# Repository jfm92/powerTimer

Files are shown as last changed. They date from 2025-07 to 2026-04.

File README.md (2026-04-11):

# Power Timer

## Project Description

The Power Timer is an ultra-low power module that allows you to control the output power by software. It is mainly based on a Real-Time Clock (RTC) and an RS circuit. Thanks to the RTC, you can control the exact wake-up date or the periodicity. It also allows for external interruptions, which gives you the benefits of ultra-low power consumption while being able to connect other types of sensors. The module is based on the RV3028-C7 chip. It is also compatible with Arduino, thanks to its custom library.

The sleep current of the module is around 50nA at 3.3V, making it ideal for battery-powered applications.



## Consumption comparison:

Demo with software **sleep modes**:

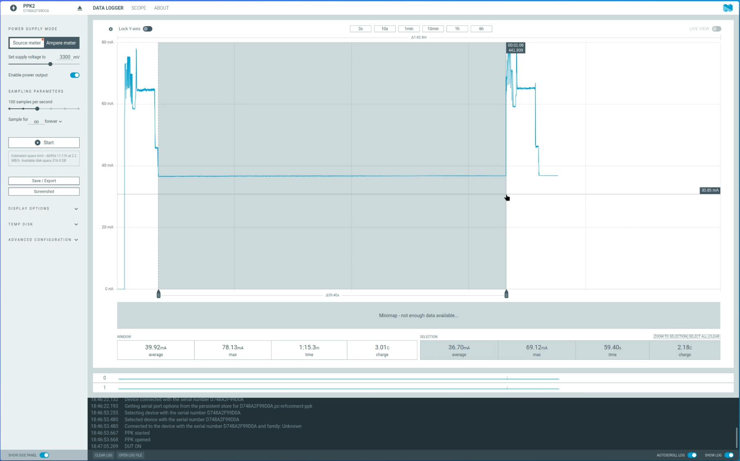
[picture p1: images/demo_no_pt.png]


Same demo **with powerTimer**:

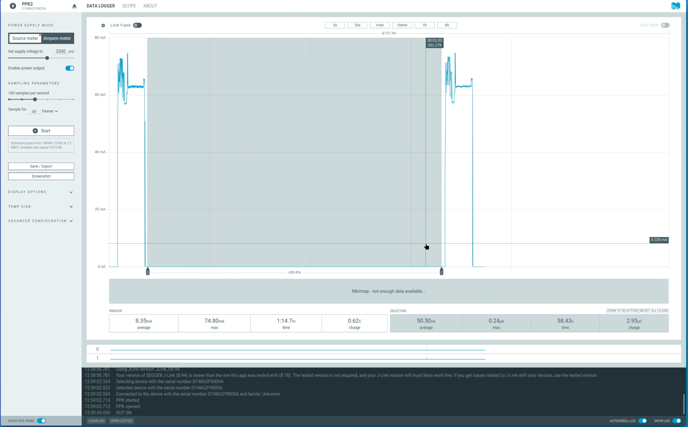
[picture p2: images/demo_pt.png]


### 734.000 times less idle consumption!

## How it works

The module is designed to be a versatile power control unit for your projects. It can be used as a simple timer to power on a device at a specific time or periodically, or it can be used as a power management unit that can be woken up by external events.

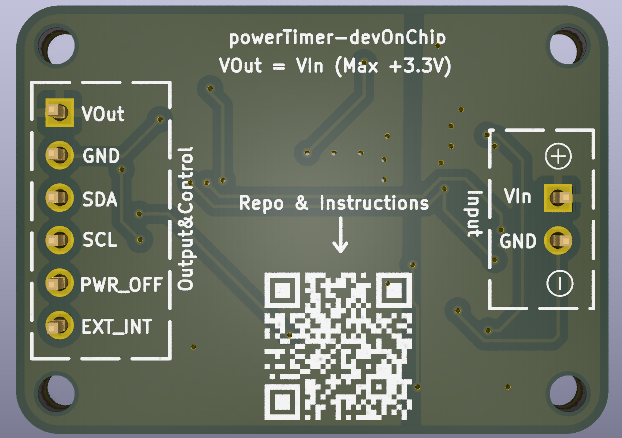
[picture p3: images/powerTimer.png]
Power Timer Diagram


The PCB is divided into two parts:

*   **Input:** The input voltage (VINput) can be from 1.1V to 5.5V. This wide input range makes it compatible with a variety of power sources, from a single-cell Li-Po battery to a 5V power supply.

*   **Output:**
    *   **I2C:** The I2C pins (SDA and SCL) are used to program the RV3028-C7 RTC. You can set the time, date, and alarms using any microcontroller with I2C capabilities.
    *   **VOutput:** This pin will provide the same voltage as the input. When the module is in the "ON" state, the VOutput pin is connected to the VINput pin, providing power to your external device.
    *   **PWR_OFF:** This input allows you to externally cut off the power of the module. By pulling this pin high, you can force the module into the "OFF" state, even if the RTC alarm is active.
    *   **EXT_INT:** This input allows you to wake up the module externally using another sensor. This is useful for applications where you want to wake up the main device based on an external event, such as a button press or a sensor reading.
    *   **On-board button:** A push button is available on the board for manual wake-up. This allows you to turn on the module without relying on the RTC alarm or an external interrupt.

The logic levels of the I2C bus and the external interrupt input depend on the selected input voltage.

## Schematic

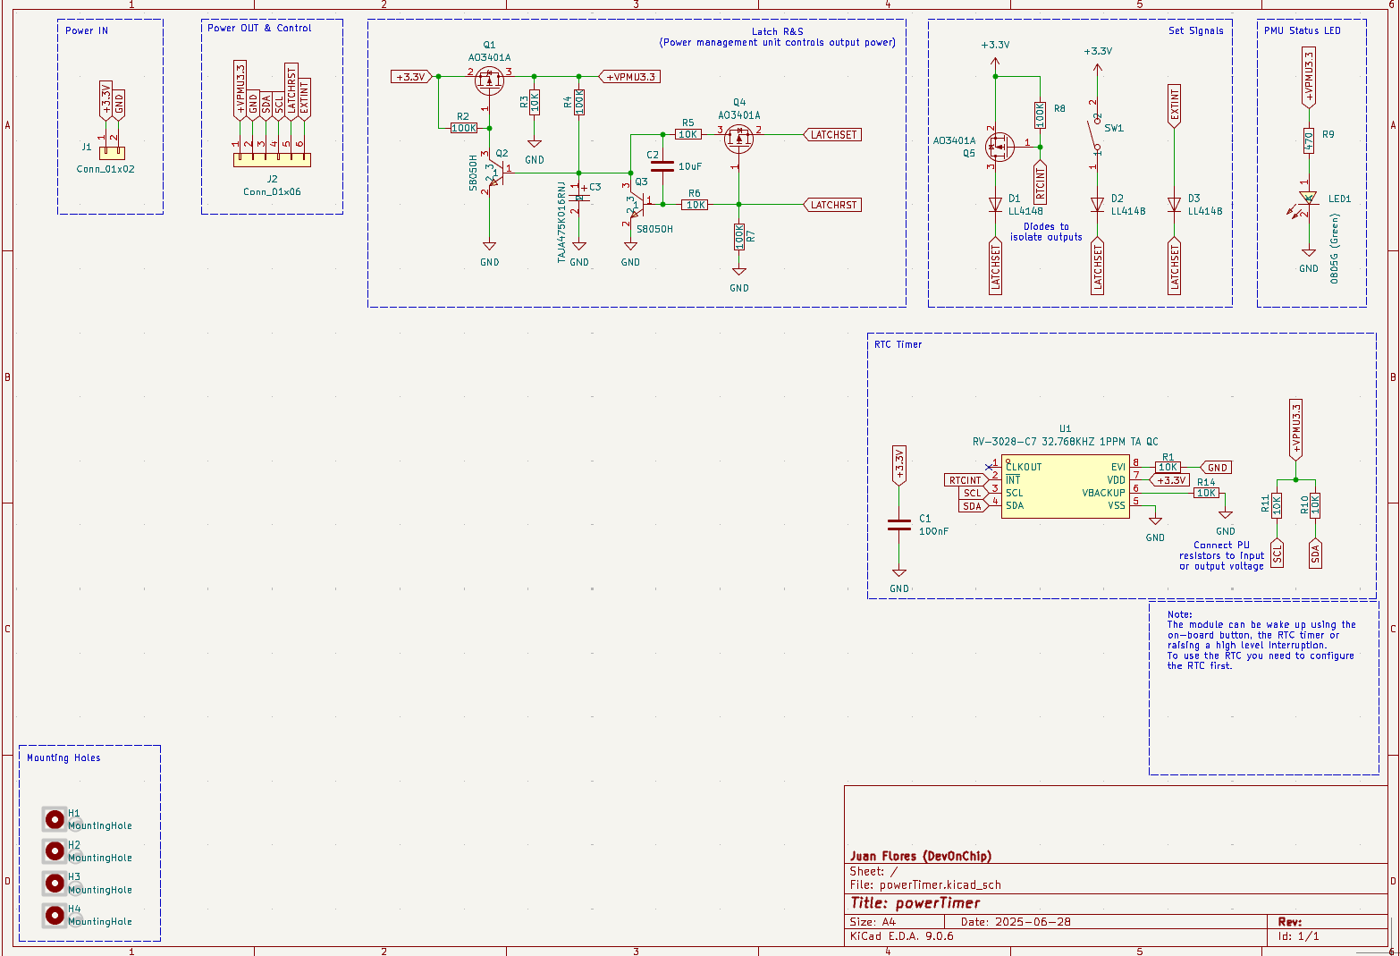
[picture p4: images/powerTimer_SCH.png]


## PCB Layout

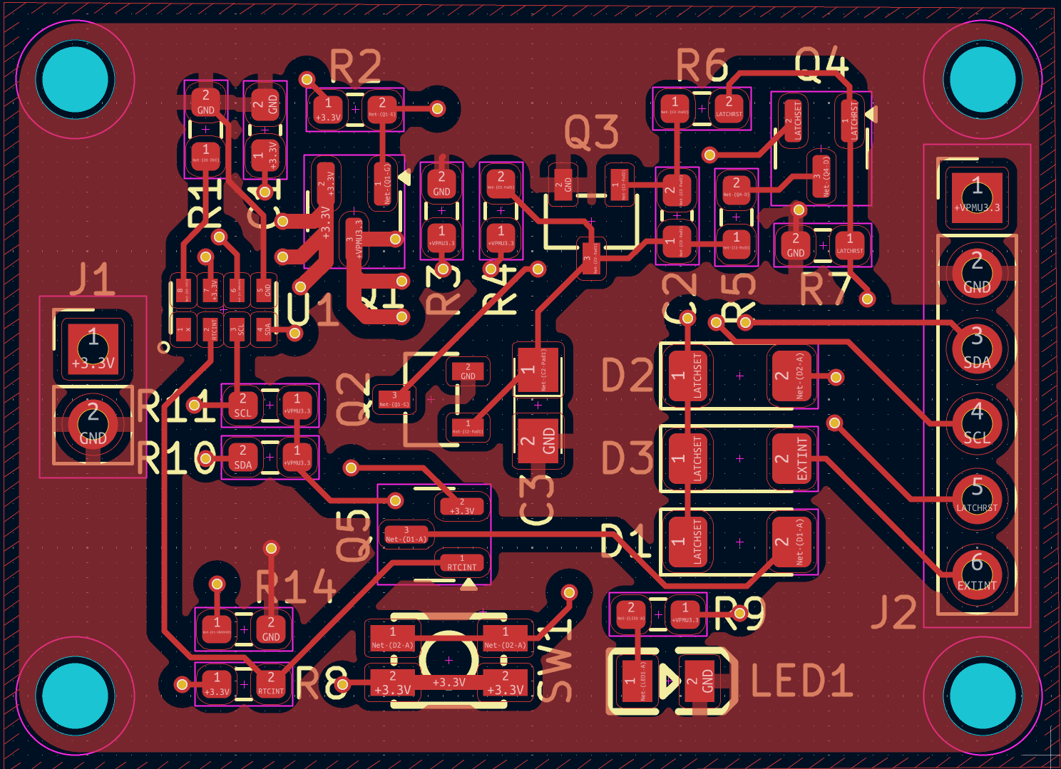
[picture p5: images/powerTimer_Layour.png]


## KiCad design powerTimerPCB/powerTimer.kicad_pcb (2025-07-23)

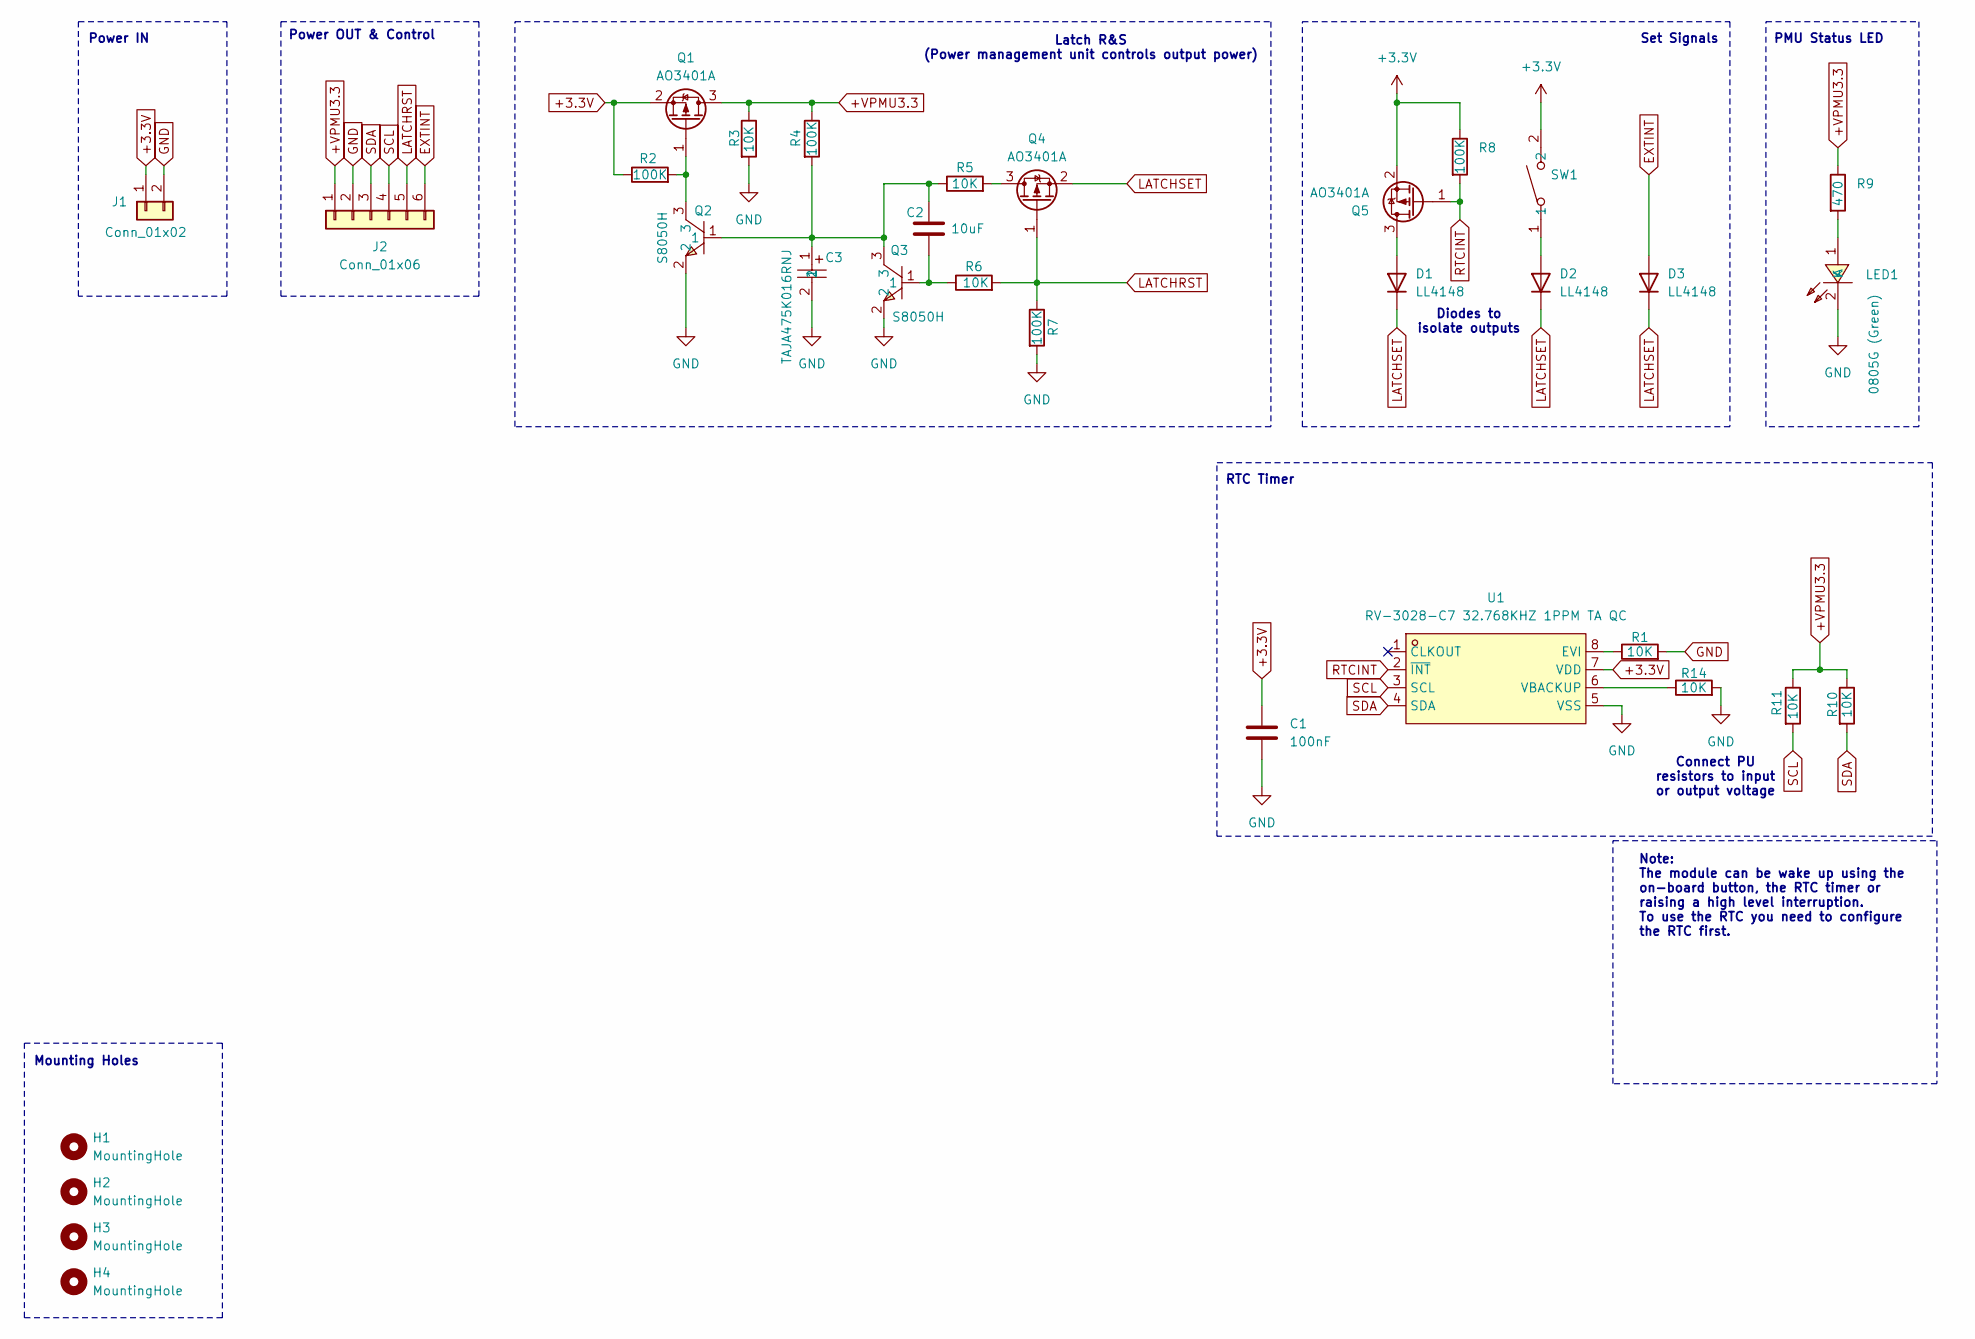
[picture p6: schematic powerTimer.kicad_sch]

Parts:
C1: 100nF; C_0603_1608Metric_Pad1.08x0.95mm_HandSolder
C2: 10uF; C_0603_1608Metric_Pad1.08x0.95mm_HandSolder
C3: TAJA475K016RNJ; CASE-A_3216; LCSC Part C7187
D1, D2, D3: LL4148; D_MiniMELF
H1, H2, H3, H4: MountingHole; MountingHole_2.2mm_M2_ISO7380
J1: Conn_01x02; PinHeader_1x02_P2.54mm_Vertical
J2: Conn_01x06; PinHeader_1x06_P2.54mm_Vertical
LED1: 0805G (Green); LED0805-R-RD; LCSC Part C2297
Q1, Q4, Q5: AO3401A; SOT-23
Q2, Q3: S8050H; SOT-23-3_L2.9-W1.6-P1.90-LS2.8-BR; LCSC Part C111272
R1, R3, R5, R6, R10, R11, R14: 10K; R_0603_1608Metric_Pad0.98x0.95mm_HandSolder
R2, R4, R7, R8: 100K; R_0603_1608Metric_Pad0.98x0.95mm_HandSolder
R9: 470; R_0603_1608Metric_Pad0.98x0.95mm_HandSolder
SW1: TS-1185EC-C-D-B; SW-SMD_4P-L3.7-W3.0-P1.50-LS4.7; LCSC Part C318893
U1: RV-3028-C7 32.768KHZ 1PPM TA QC; OSC-SMD_8P-L3.2-W1.5-P0.90-BL; LCSC Part C3019759

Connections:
+3.3V: C1.1, J1.1, Q1.2 (S), Q5.2 (S), R2.1, R8.1, SW1.2, U1.7 (VDD)
+VPMU3.3: J2.1, Q1.3 (D), R3.1, R4.1, R9.1, R10.1, R11.1
EXTINT: D3.2 (A), J2.6
GND: C1.2, C3.2, J1.2, J2.2, LED1.2 (K), Q2.2, Q3.2, R1.2, R3.2, R7.2, R14.2, U1.5 (VSS)
LATCHRST: J2.5, Q4.1 (G), R6.2, R7.1
LATCHSET: D1.1 (K), D2.1 (K), D3.1 (K), Q4.2 (S)
unnamed: C2.1, C3.1, Q2.1, Q3.3, R4.2, R5.1
unnamed: C2.2, Q3.1, R6.1
unnamed: D1.2 (A), Q5.3 (D)
unnamed: D2.2 (A), SW1.1
unnamed: LED1.1 (A), R9.2
unnamed: Q1.1 (G), Q2.3, R2.2
unnamed: Q4.3 (D), R5.2
unnamed: R1.1, U1.8 (EVI)
unnamed: R14.1, U1.6 (VBACKUP)
RTCINT: Q5.1 (G), R8.2, U1.2 (~INT)
SCL: J2.4, R11.2, U1.3 (SCL)
SDA: J2.3, R10.2, U1.4 (SDA)

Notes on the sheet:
RTC Timer
Latch R&S (Power management unit controls output power)
Note: The module can be wake up using the on-board button, the RTC timer or raising a high level interruption. To use the RTC you need to configure the RTC first.
Power OUT & Control
Set Signals
PMU Status LED
Power IN
Mounting Holes
Diodes to isolate outputs
Connect PU resistors to input or output voltage

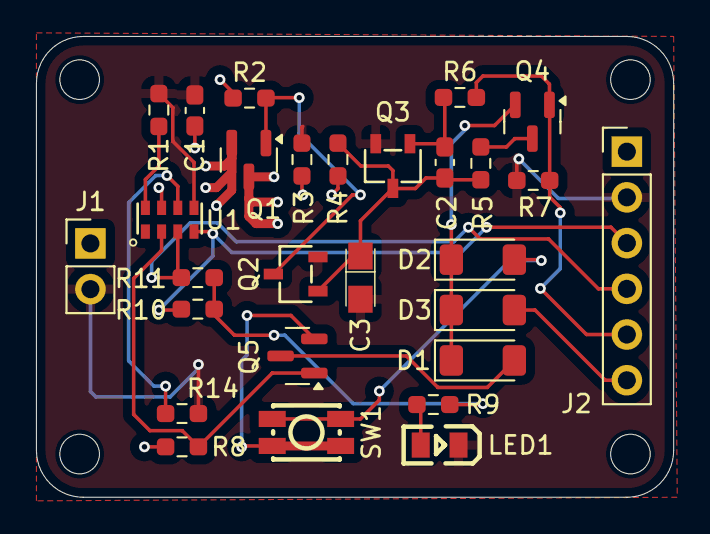
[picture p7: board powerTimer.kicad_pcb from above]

Board: 2 copper layers, 35.4 x 25.6 mm, 32 parts (0 on the bottom side), 18 nets.

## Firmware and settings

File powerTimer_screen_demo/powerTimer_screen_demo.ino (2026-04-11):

#include <lvgl.h>
#include <Arduino_GFX_Library.h>
#include <SPI.h>
#include <Wire.h>
#include <Adafruit_Sensor.h>
#include "Adafruit_BME680.h"

#include "powerTimer.h"
#include "Wire.h"

#define TFT_CS    11
#define TFT_DC    10
#define TFT_MOSI   6
#define TFT_SCLK   5
#define TFT_RST    7
#define TFT_BL    -1

#define SDA_PIN 22
#define SCL_PIN 23
#define POWER_OFF_PIN 3

#define SCREEN_W 320
#define SCREEN_H 206
#define BUF_LINES 30

#define DISPLAY_ON_TIME 5 //Secs
#define TIME_TO_SLEEP  60 //Secs

#define POWER_TIMER_ON

#ifdef POWER_TIMER_ON
  powerTimer powerTimer;
#endif

Adafruit_BME680 bme(&Wire); 

static lv_color_t draw_buf_data[SCREEN_W * BUF_LINES];
static lv_display_t *display;

static lv_obj_t *lbl_temp_val;
static lv_obj_t *lbl_hum_val;
static lv_obj_t *lbl_status;

Arduino_DataBus *bus = new Arduino_ESP32SPI(
    TFT_DC,    // DC
    TFT_CS,    // CS
    TFT_SCLK,  // SCLK
    TFT_MOSI,  // MOSI
    -1       // Not MISO
);

Arduino_ST7789 *tft = new Arduino_ST7789(bus, TFT_RST, 1, true,
                                          SCREEN_H , SCREEN_W,
                                          0, 0);

// ─── Flush ──────────────────────────────────────────────────
void my_disp_flush(lv_display_t *disp, const lv_area_t *area, uint8_t *px_map) {
    tft->draw16bitRGBBitmap(area->x1 , area->y1+20, (uint16_t *)px_map,
                            area->x2 - area->x1 + 1,
                            area->y2 - area->y1 + 1);
    lv_display_flush_ready(disp);
}

// ─── Meas Card ───────────────────────────────────────────
void create_card(lv_obj_t   *parent,
                 int         x,
                 const char *titulo,
                 const char *unidad,
                 lv_color_t  color,
                 lv_obj_t  **out_label)
{
    lv_obj_t *card = lv_obj_create(parent);
    lv_obj_set_size(card, 148, 150);
    lv_obj_align(card, LV_ALIGN_LEFT_MID, x, 0);
    lv_obj_set_style_bg_color(card, lv_color_hex(0x0d1b2a), LV_PART_MAIN);
    lv_obj_set_style_border_color(card, color, LV_PART_MAIN);
    lv_obj_set_style_border_width(card, 2, LV_PART_MAIN);
    lv_obj_set_style_radius(card, 16, LV_PART_MAIN);
    lv_obj_set_style_pad_all(card, 0, LV_PART_MAIN);
    lv_obj_set_style_shadow_color(card, color, LV_PART_MAIN);
    lv_obj_set_style_shadow_width(card, 14, LV_PART_MAIN);
    lv_obj_set_style_shadow_opa(card, LV_OPA_30, LV_PART_MAIN);
    lv_obj_clear_flag(card, LV_OBJ_FLAG_SCROLLABLE);

    // Tittle
    lv_obj_t *lbl_titulo = lv_label_create(card);
    lv_label_set_text(lbl_titulo, titulo);
    lv_obj_set_style_text_font(lbl_titulo, &lv_font_montserrat_14, LV_PART_MAIN);
    lv_obj_set_style_text_color(lbl_titulo, color, LV_PART_MAIN);
    lv_obj_set_style_text_letter_space(lbl_titulo, 2, LV_PART_MAIN);
    lv_obj_align(lbl_titulo, LV_ALIGN_TOP_MID, 0, 12);

    // Separator
    lv_obj_t *sep = lv_obj_create(card);
    lv_obj_set_size(sep, 110, 1);
    lv_obj_align(sep, LV_ALIGN_TOP_MID, 0, 36);
    lv_obj_set_style_bg_color(sep, color, LV_PART_MAIN);
    lv_obj_set_style_bg_opa(sep, LV_OPA_40, LV_PART_MAIN);
    lv_obj_set_style_border_width(sep, 0, LV_PART_MAIN);
    lv_obj_set_style_radius(sep, 0, LV_PART_MAIN);

    // Value
    lv_obj_t *lbl_val = lv_label_create(card);
    lv_label_set_text(lbl_val, "--");
    lv_obj_set_style_text_font(lbl_val, &lv_font_montserrat_28, LV_PART_MAIN);
    lv_obj_set_style_text_color(lbl_val, lv_color_hex(0xffffff), LV_PART_MAIN);
    lv_obj_align(lbl_val, LV_ALIGN_CENTER, 0, 6);
    *out_label = lbl_val;

    // Unit
    lv_obj_t *lbl_unit = lv_label_create(card);
    lv_label_set_text(lbl_unit, unidad);
    lv_obj_set_style_text_font(lbl_unit, &lv_font_montserrat_20, LV_PART_MAIN);
    lv_obj_set_style_text_color(lbl_unit, lv_color_hex(0xffffff), LV_PART_MAIN);
    lv_obj_align(lbl_unit, LV_ALIGN_BOTTOM_MID, 0, -10);
}

// ─── Main UI ───────────────────────────────────────────
void create_ui() {
    lv_obj_t *scr = lv_scr_act();
    lv_obj_set_style_bg_color(scr, lv_color_hex(0x060d17), LV_PART_MAIN);
    lv_obj_clear_flag(scr, LV_OBJ_FLAG_SCROLLABLE);

    // Temperature card — left
    create_card(scr,
                8,
                "TEMPERATURE",
                "\xC2\xB0""C",
                lv_color_hex(0xff6b6b),
                &lbl_temp_val);

    // Humidity card — rigth
    create_card(scr,
                164,
                "HUMIDITY",
                "%",
                lv_color_hex(0x00d4ff),
                &lbl_hum_val);
}

// ─── Update sensor values───────────────────────────────────────
void update_sensors(float temp, float hum) {
    char buf[12];

    snprintf(buf, sizeof(buf), "%.1f", temp);
    lv_label_set_text(lbl_temp_val, buf);

    snprintf(buf, sizeof(buf), "%.1f", hum);
    lv_label_set_text(lbl_hum_val, buf);
}

void setup() {
    Serial.begin(115200);

    //I2C Init
    Wire.begin(SDA_PIN,SCL_PIN);

    #ifdef POWER_TIMER_ON
      if(!powerTimer.begin(POWER_OFF_PIN)){
          Serial.println("powerTimer Intialization failed.");
          while (1);
      }
    #endif

    if (!bme.begin()) {
      Serial.println("Could not find a valid BME680 sensor, check wiring!");
      #ifdef POWER_TIMER_ON
        powerTimer.powerOff();
      #else
        while(1);
      #endif
    }

    //Sensor Config
    bme.setTemperatureOversampling(BME680_OS_8X);
    bme.setHumidityOversampling(BME680_OS_2X);
    bme.setPressureOversampling(BME680_OS_4X);
    bme.setIIRFilterSize(BME680_FILTER_SIZE_3);
    bme.setGasHeater(320, 150); // 320*C for 150 ms

    //Sensor measurement
    if (!bme.performReading()) {
      Serial.println("Failed to perform reading :(");
      #ifdef POWER_TIMER_ON
        powerTimer.powerOff();
      #else
        while(1);
      #endif
    }

    float temperature = bme.temperature;
    float humidity = bme.humidity;

    tft->begin();
    
    // UI Initialization
    lv_init();

    display = lv_display_create(SCREEN_W, SCREEN_H);

    lv_display_set_flush_cb(display, my_disp_flush);
    lv_display_set_buffers(display, draw_buf_data, NULL,
                           sizeof(draw_buf_data),
                           LV_DISPLAY_RENDER_MODE_PARTIAL);
    create_ui();
    
    update_sensors(temperature, humidity);
}

void loop() {
    lv_timer_handler();

    static uint32_t last = 0;
    if (millis() - last > DISPLAY_ON_TIME*1000) {
        last = millis();
        
        #ifdef POWER_TIMER_ON
          if(powerTimer.readAlarmInterruptFlag()){
              Serial.println("Device wake by alarm interrupt.");
              powerTimer.clearAlarmInterruptFlag();
          }

          //Reset RTC
          powerTimer.clearInterrupts();
          if(powerTimer.setTime(0,0,0,1,1,1,2025)){
              Serial.println("Error setting date.");
              powerTimer.powerOff();
          }

          powerTimer.enableAlarmInterrupt(1, 0, 1, false);
          Serial.println("Alarm interrupt enable in 1 minute.");

          powerTimer.powerOff();
        #else
          esp_sleep_enable_timer_wakeup(TIME_TO_SLEEP * 1000000ULL);
          Serial.println("Setup ESP32 to sleep for every " + String(TIME_TO_SLEEP) + " Seconds");
          esp_deep_sleep_start();
        #endif

    }

    delay(5);
}

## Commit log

2025-06-28 Adding PCB design
    [powerTimer.kicad_pcb, powerTimer.kicad_sch]
2025-07-23 Minor change on MOSFET Q5 polarity
    [powerTimer.kicad_pcb, powerTimer.kicad_sch]
2025-09-13 Adding driver to the main repo
2026-04-10 Adding powerProfiler images
